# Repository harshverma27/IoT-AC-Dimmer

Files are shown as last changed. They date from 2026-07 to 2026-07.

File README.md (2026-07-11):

# IoT AC Dimmer

ESP32-based wireless phase-angle AC dimmer. Two PCBs linked over ESP-NOW:
a mains-side dimmer board that switches a TRIAC, and a battery-powered
remote with three buttons. Source spec: `IoT AC Dimmer Project.docx`
(v2.0, March 2026).

## What's in this repo

- **Dimmer board** (`hardware/dimmer/`) — 230V mains input, zero-cross
  detection, phase-angle TRIAC control (up to ~2000W / 12A), ESP32 DevKit V1
  running ESP-NOW RX + WiFi.
- **Remote board** (`hardware/remote/`) — LiPo-powered, 3 tactile buttons
  (UP / DOWN / ON-OFF), ESP32 DevKit V1 in deep sleep, ESP-NOW TX only.
- **Generator scripts** (`hardware/tools/`) — Python scripts (on top of
  `kiutils`) that bootstrapped the schematic captures for both boards, so
  the design is reproducible and diffable.

Both boards are designed in KiCad 10. Schematics for both boards are
captured and validated against a `kicad-cli`-exported netlist. PCB layout
is in progress (remote board has a first-pass placement + routing; dimmer
board layout is next).

## Repo layout

```
hardware/
  dimmer/     KiCad project — mains dimmer board (schematic + PCB)
  remote/     KiCad project — battery remote board (schematic + PCB)
  tools/      Python scripts that generated the schematic captures
IoT AC Dimmer Project.docx   Design spec (source of truth for requirements)
CLAUDE.md                    Detailed design notes, GPIO maps, part list
```

See `hardware/README.md`, `hardware/tools/README.md`, and `CLAUDE.md` for
full detail — part lists, GPIO pin maps, and design rationale.

## ⚠️ Safety notice

The dimmer board connects directly to 230V AC mains. It uses an opto-isolated
zero-cross detector (TLP281-4) and an opto-isolated TRIAC driver (MOC3021)
to keep mains-side and logic-side circuitry galvanically isolated, with a
routed FR4 isolation slot under both optoisolators. Do not bridge that
isolation slot with copper or traces, and do not power the dimmer board from
mains and USB at the same time. If you build this, treat it as a mains-voltage
project: use proper enclosures, creepage/clearance spacing, and fusing, and
follow your local electrical code. Build and use at your own risk.

## Hardware overview

### Dimmer board

| Block | Part | Notes |
|---|---|---|
| MCU | ESP32 DevKit V1 (30-pin plug-in module) | Core 0: phase timing ISR. Core 1: WiFi/ESP-NOW/MQTT |
| PSU | HLK-PM03 | Isolated 230V→3.3V/900mA, feeds DevKit 3V3 directly (no LDO) |
| AC in/out | MKDSN 5.08mm screw terminals | Live + Neutral |
| Zero-cross detect | TLP281-4 opto + 1N4007 + resistors | 3.3V pulses into GPIO34 |
| Gate drive | MOC3021 opto + resistor | Drives TRIAC gate from GPIO25 |
| Power switch | BT138-600 TRIAC + gate resistor + RC snubber | ~2000W max (12A) |
| Programming | Onboard CP2102 + micro-USB on the DevKit itself | No separate USB circuitry on the carrier board |

### Remote board

| Block | Part | Notes |
|---|---|---|
| Battery | LiPo 500mAh 3.7V, JST-PH | Rechargeable |
| Charger | TP4056 charge/protect module (USB-C) | Handles charging, protection, and status LEDs |
| LDO | ME6211 3.3V SOT-23-5 | Regulates battery voltage down to clean 3.3V |
| MCU | ESP32 DevKit V1 (30-pin plug-in module) | ext1 button wakeup, ESP-NOW TX, deep sleep between presses |
| Buttons | 3× 6×6mm tactile THT, pull-up + debounce RC | UP / DOWN / ON-OFF |

Full GPIO maps, exact part numbers, and design rationale (including the
plug-in-DevKit battery-life tradeoff on the remote) live in `CLAUDE.md`.

## Getting started

Requires KiCad 10.

```bash
kicad hardware/dimmer/dimmer.kicad_pro
kicad hardware/remote/remote.kicad_pro
```

The `.kicad_sch` files are KiCad-7 format; KiCad 10 opens and upgrades them
automatically. Don't hand-edit the format version token — see
`hardware/tools/README.md` for why.

To regenerate a schematic capture from the Python generators:

```bash
cd hardware/tools
pip install kiutils
python3 gen_dimmer.py
python3 gen_remote.py
python3 validate.py ../dimmer/dimmer.kicad_sch ../remote/remote.kicad_sch
```

## Status

- Schematics: captured and validated for both boards.
- PCB layout: remote board has first-pass placement/routing; dimmer board
  layout not yet started.
- Firmware: not yet in this repo.

## Firmware plan (not yet implemented)

- Dimmer: hardware timer ISR on Core 0 sets TRIAC fire delay after each
  zero crossing (phase-angle dimming). Networking (WiFi/ESP-NOW/MQTT)
  stays on Core 1.
- Remote: wake on button press (`ext1`), send an ESP-NOW packet, go back
  to deep sleep.
- Future: MQTT + OTA on the dimmer; BLE + display on the remote.

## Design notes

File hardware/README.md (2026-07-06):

# Hardware

Two KiCad 10 boards. See root `CLAUDE.md` for the full design spec.

| Dir | Board | Notes |
|-----|---|---|
| `dimmer/` | Mains-side AC dimmer | 230V, TRIAC phase control, ESP-NOW RX + WiFi. **Isolation slot required.** |
| `remote/` | Battery remote | LiPo, 3 buttons, ESP-NOW TX, deep sleep |

Each dir holds `*.kicad_pro` / `*.kicad_sch` / `*.kicad_pcb`.

## Status
- **Schematics: captured** for both boards (`dimmer.kicad_sch`, `remote.kicad_sch`).
  Validated by `kicad-cli` netlist export — every functional net matches intent.
- **PCB layout: not started** (`*.kicad_pcb` still blank) — next phase.

The capture was bootstrapped by the scripts in `tools/` (see `tools/README.md`);
the `.kicad_sch` files are the source of truth.

| Board | Parts placed | Key nets |
|---|---|---|
| dimmer | 31 | mains L/N/L_OUT, ZC detect → GPIO34, gate drive → GPIO25, +3V3/+5V, USB/UART, auto-reset |
| remote | 34 | VBUS/VBAT/+3V3 power path, BTN_UP/DOWN/ONOFF (GPIO39/34/35), USB/UART, auto-reset |

## Workflow
- Open a board: `kicad hardware/dimmer/dimmer.kicad_pro`
  (schematics are KiCad-7 format `20230121`; KiCad 9/10 opens and upgrades them).
- Next: assign/refine footprints, then lay out the PCB — remember the **isolation
  slot** under U2/U3 on the dimmer.
- Analysis / review / BOM / fab: use the **kicad-happy** skills (kicad, bom, jlcpcb, emc…).

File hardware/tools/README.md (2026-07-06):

# Schematic capture generator

Scripts that generated the initial schematic capture for both boards. The
`.kicad_sch` files are the source of truth — these scripts just bootstrapped
them so the capture is reproducible and reviewable in a diff.

| File | Purpose |
|---|---|
| `schlib.py` | Thin KiCad-schematic builder on top of [`kiutils`](https://pypi.org/project/kiutils/): embeds stdlib symbols, builds custom rectangular symbols, places parts, and wires nets with labels + power ports. |
| `parts.py` | Custom symbols for parts / modules absent from the KiCad standard library (HLK-PM03, TLP281-4, MOC3021, ME6211, ESP32-DevKitC-30 plug-in module, TP4056 charge+protect module), with datasheet-accurate pinouts. |
| `gen_dimmer.py` | Builds `../dimmer/dimmer.kicad_sch`. |
| `gen_remote.py` | Builds `../remote/remote.kicad_sch`. |
| `validate.py` | ERC-lite: rebuilds the netlist from geometry + label names and reports nets / floating pins. |

## Regenerate

```bash
pip install kiutils
# KiCad standard symbol libraries are read from /usr/share/kicad/symbols
python3 gen_dimmer.py
python3 gen_remote.py
python3 validate.py ../dimmer/dimmer.kicad_sch ../remote/remote.kicad_sch
```

## Validation performed

Both schematics were loaded by a real `kicad-cli` (`sch export netlist`) and the
KiCad-computed netlist was cross-checked against the intended connectivity —
every functional net matches. The only unconnected pins are spare ESP32 GPIOs,
which are intentional (fixed-function boards, no breakout header in the spec).

## File format note

The schematics are written in KiCad-7 schematic format (`version 20230121`),
which is what `kiutils` emits. KiCad 9/10 opens them directly and will offer to
save in the newer format. Do not hand-edit the version token — the per-symbol
`instances` blocks require `>= 20230121` to be read correctly.

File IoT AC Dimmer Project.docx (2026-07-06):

IoT AC Power Dimmer

with ESP32 + ESP-NOW Wireless Remote

Project Design Document | March 2026

Project Summary

A two-board wireless AC dimmer using ESP32 microcontrollers on both the dimmer and remote. The dimmer board connects to 230V mains and uses phase-angle TRIAC control. The remote runs on a 3.7V LiPo battery with USB-C charging via TP4056. Both boards communicate over ESP-NOW..

Parameter | Dimmer Board | Remote Board
MCU | ESP32-WROOM-32 (240MHz dual-core) | ESP32-WROOM-32 (240MHz dual-core)
Wireless | ESP-NOW RX + WiFi (simultaneous) | ESP-NOW TX only (on wakeup)
Power supply | HLK-PM03 (230V→5V direct) | 3.7V LiPo + TP4056
AC control | TLP281-4 + MOC3021 + BT138 | None
Max load | ~2000W (BT138 12A) | —
Phase timing | hw_timer_t Core 0 (hardware ISR) | —
Sleep current | ~120mA (PSU dominant) | ~5µA deep sleep
Battery life | — | ~4-6 months (500mAh LiPo)
Programming | USB-C via CP2102 on-board | USB-C via CP2102 on-board
Future expansion | MQTT over WiFi, OTA updates | BLE, display add-on possible

# 1. Project Overview

We will make both the ESPs communicate with each other and with the remote board’s instruction, the dimmer board will adjust the AC Supply.

# 2. System Architecture

## 2.1 Dimmer board block diagram

Block | Component | Function
AC IN | MKDSN 5.08mm screw terminal | Live + Neutral mains input
Isolated PSU | HLK-PM03 | 230V AC to 3.3V/900mA, isolated. No LDO needed.
ZC detector | TLP281-4 + R1 10kΩ + D1 1N4007 + R2 10kΩ pull-up | Detects mains zero crossings, outputs 3.3V pulses to GPIO34
Gate drive | MOC3021 + R3 330Ω | Optoisolated TRIAC gate trigger from GPIO25
Power switch | BT138-600 TRIAC + R4 470Ω gate + R5+C5 snubber | Controls AC power to load
MCU | ESP32-WROOM-32 | Core 0: phase timing. Core 1: WiFi + ESP-NOW + MQTT
Programming | CP2102 USB-Serial + USB-C + auto-reset circuit | Flash firmware without ST-Link
AC OUT | MKDSN 5.08mm screw terminal | Output to load
PCB slot | Routed cutout in FR4 | Galvanic isolation under TLP281-4 and MOC3021

## 2.2 Remote board block diagram

Block | Component | Function
Battery | LiPo 500mAh 3.7V (JST-PH) | Main power source, rechargeable
Charger | TP4056 module | USB-C to LiPo 1A
LDO | ME6211 3.3V SOT-23-5 | 3.7V LiPo to regulated 3.3V for ESP32
MCU | ESP32-WROOM-32 | Deep sleep, ext1 wakeup on buttons, ESP-NOW TX
Buttons | 3x tactile 6x6mm + 100kΩ pull-up + 100nF debounce | UP / DOWN / ON-OFF
Programming | CP2102 USB-Serial + USB-C | Firmware flashing
Wakeup pins | GPIO39, GPIO34, GPIO35 (RTC GPIOs) | Only RTC GPIOs survive deep sleep for ext1 wakeup

# 3. Circuit Diagrams

## 3.1 Dimmer board

The HLK-PM03 outputs 3.3V directly — no AMS1117 LDO is needed, simplifying the board significantly compared to v1.0. The TLP281-4 ZC detector feeds GPIO34 (input-only RTC GPIO). The MOC3021 gate drive receives its signal from GPIO25 via R3 330Ohm. The BT138 TRIAC fires after a delay set by hw_timer_t on Core 0. The CP2102 USB-Serial chip enables programming directly from USB-C without any external programmer.

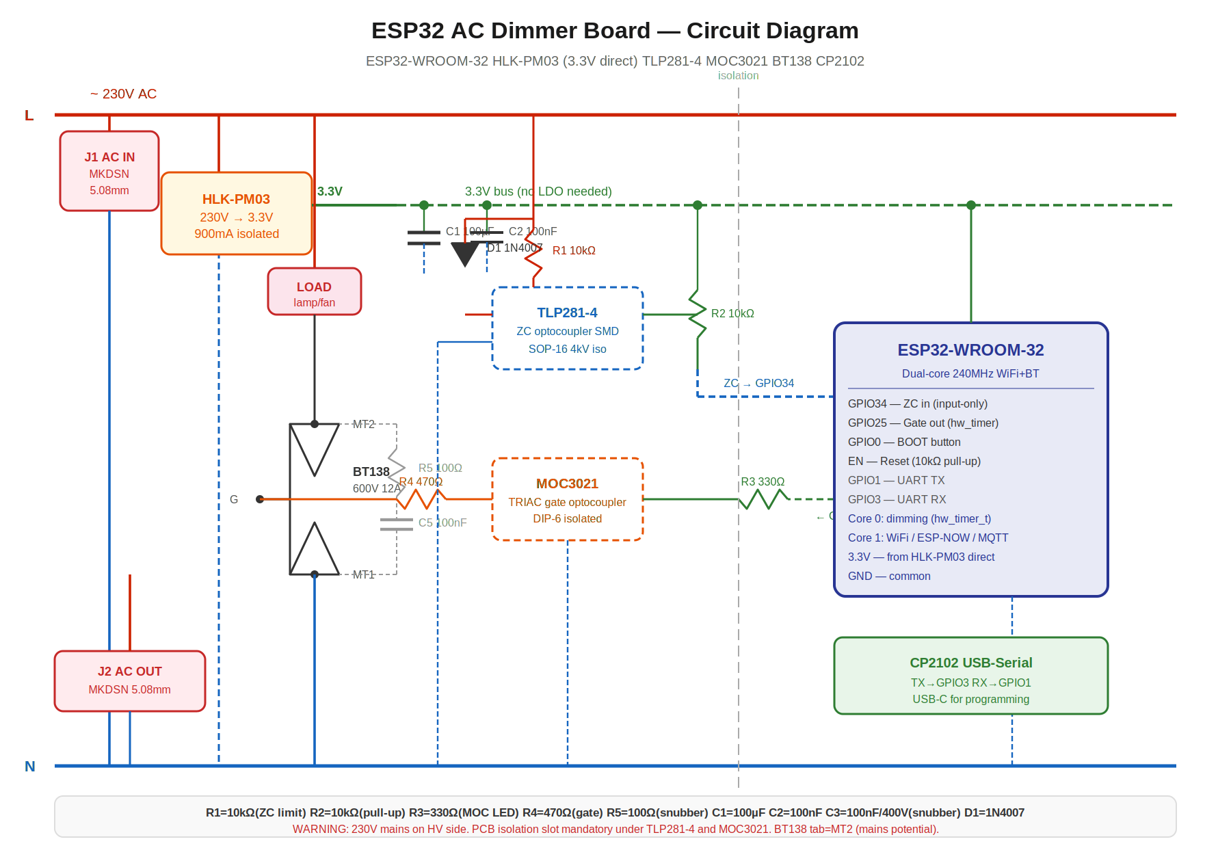
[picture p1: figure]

Figure 1 — ESP32 Dimmer Board. Red rails = 230V AC. Green dashed = 3.3V bus. Note: HLK-PM03 directly outputs 3.3V — no LDO between PSU and ESP32.

## 3.2 Remote board

The LiPo battery feeds the TP4056 charger (which also accepts USB-C input) and the ME6211 LDO simultaneously. The ME6211 regulates 3.7V to a clean 3.3V for the ESP32. Buttons use 100kOhm pull-ups (not 10kOhm) to minimise leakage current during deep sleep. All three button GPIOs (39, 34, 35) are RTC-capable and used with esp_sleep_enable_ext1_wakeup(). The CP2102 provides USB-C programming.

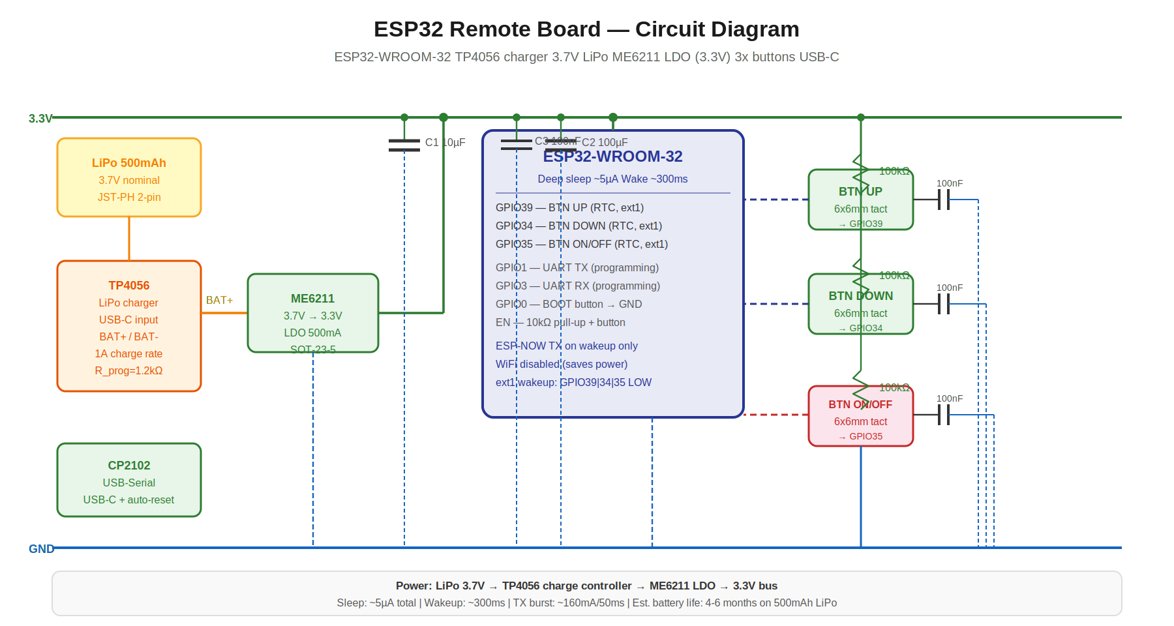
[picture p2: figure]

Figure 2 — ESP32 Remote Board. LiPo + TP4056 + ME6211 power chain. All button pins are RTC GPIOs for deep sleep ext1 wakeup.

# 4. Pin Mapping

## 4.1 Dimmer board — ESP32 GPIO assignments

GPIO | Signal | Direction | Notes
GPIO34 | ZC detect (TLP281-4 output) | Input only | Input-only RTC GPIO. No internal pull-up. Use external 10kOhm pull-up to 3.3V.
GPIO25 | TRIAC gate (MOC3021 LED via R3) | Output | DAC-capable but used as digital. hw_timer_t fires 100us pulse here.

## 4.2 Remote board — ESP32 GPIO assignments

GPIO | Signal | Direction | Notes
GPIO39 | BTN UP | Input only | RTC GPIO. Input-only. External 100kOhm pull-up to 3.3V. ext1 wakeup source.
GPIO34 | BTN DOWN | Input only | RTC GPIO. Input-only. External 100kOhm pull-up. ext1 wakeup source.
GPIO35 | BTN ON/OFF | Input only | RTC GPIO. Input-only. External 100kOhm pull-up. ext1 wakeup source.

Document prepared by Harsh | ESP32 IoT Dimmer Project v2.0 | March 2026

Page Harsh — IoT Dimmer Project

IoT AC Power Dimmer with Wireless Remote

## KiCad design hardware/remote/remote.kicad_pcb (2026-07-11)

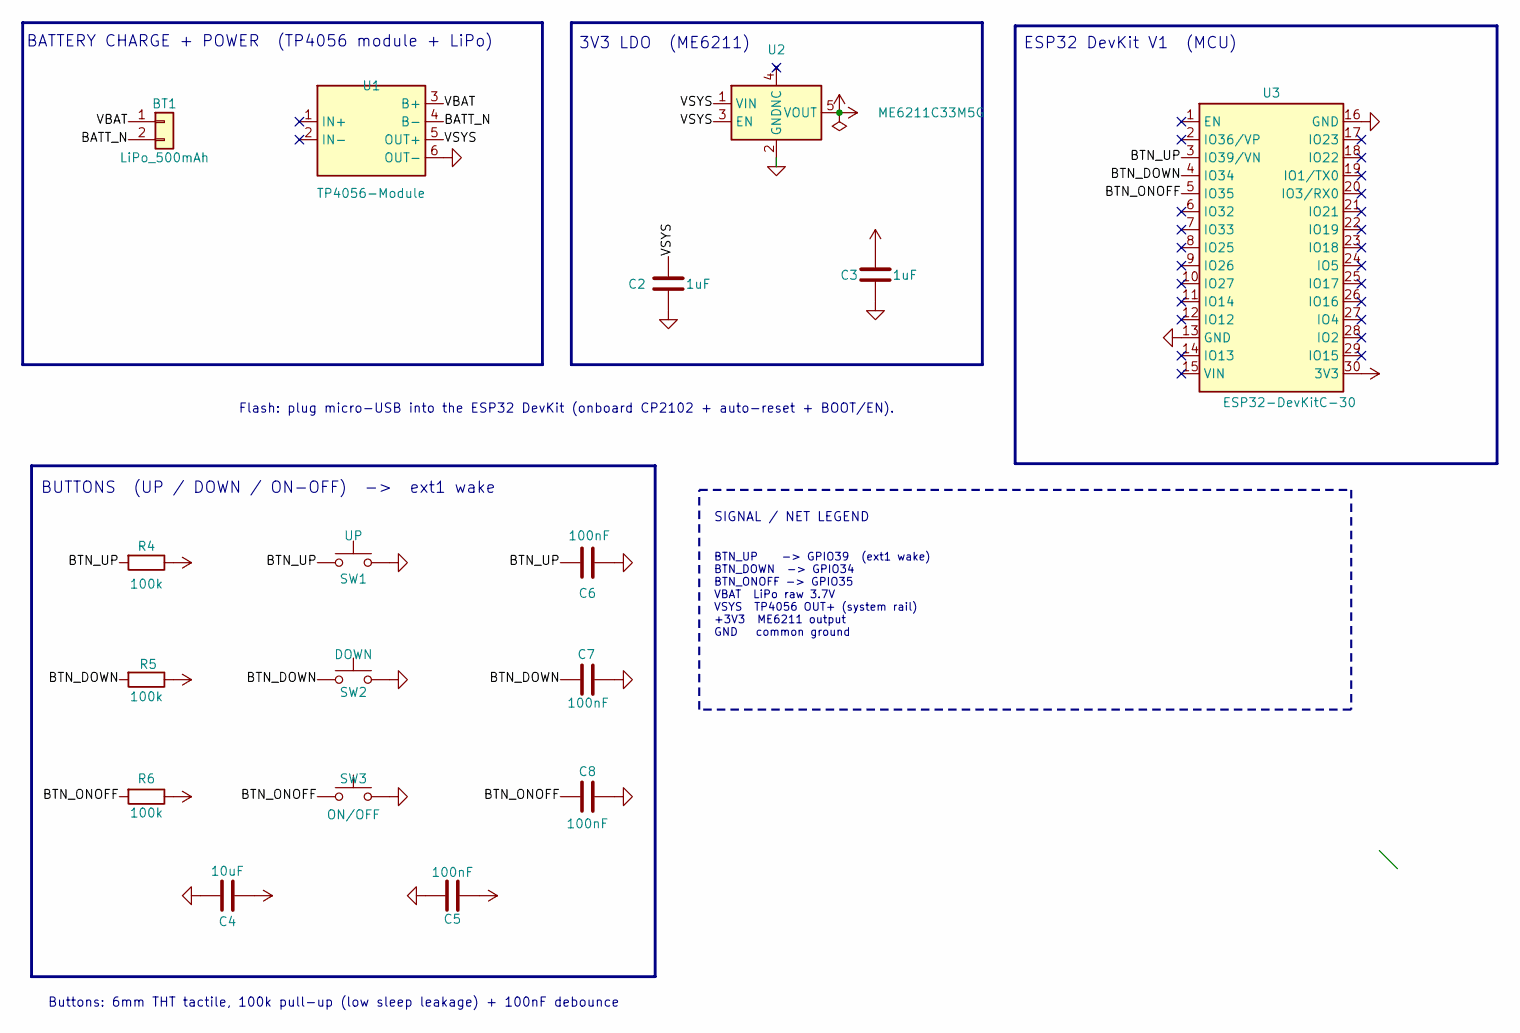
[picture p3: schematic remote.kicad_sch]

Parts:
BT1: LiPo_500mAh; JST_PH_S2B-PH-SM4-TB_1x02-1MP_P2.00mm_Horizontal
C2, C3: 1uF; C_0805_2012Metric
C4: 10uF; C_1206_3216Metric
C5, C6, C7, C8: 100nF; C_0805_2012Metric
R4, R5, R6: 100k; R_0805_2012Metric
SW1: UP; SW_PUSH_6mm
SW2: DOWN; SW_PUSH_6mm
SW3: ON/OFF; SW_PUSH_6mm
U1: TP4056-Module; PinHeader_1x06_P2.54mm_Vertical
U2: ME6211C33M5G; SOT-23-5
U3: ESP32-DevKitC-30

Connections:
+3V3: C3.1, C4.1, C5.1, R4.1, R5.1, R6.1, U2.5 (VOUT), U3.30 (3V3)
/BATT_N: BT1.2, U1.4 (B-)
/BTN_DOWN: C7.1, R5.2, SW2.1, U3.4 (IO34)
/BTN_ONOFF: C8.1, R6.2, SW3.1, U3.5 (IO35)
/BTN_UP: C6.1, R4.2, SW1.1, U3.3 (IO39/VN)
/VBAT: BT1.1, U1.3 (B+)
/VSYS: C2.1, U1.5 (OUT+), U2.1 (VIN), U2.3 (EN)
GND: C2.2, C3.2, C4.2, C5.2, C6.2, C7.2, C8.2, SW1.2, SW2.2, SW3.2, U1.6 (OUT-), U2.2 (GND), U3.13 (GND), U3.16 (GND)

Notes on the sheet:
Flash: plug micro-USB into the ESP32 DevKit (onboard CP2102 + auto-reset + BOOT/EN).
BATTERY CHARGE + POWER (TP4056 module + LiPo)
3V3 LDO (ME6211)
SIGNAL / NET LEGEND
BTN_UP -> GPIO39 (ext1 wake) BTN_DOWN -> GPIO34 BTN_ONOFF -> GPIO35 VBAT LiPo raw 3.7V VSYS TP4056 OUT+ (system rail) +3V3 ME6211 output GND common ground
Buttons: 6mm THT tactile, 100k pull-up (low sleep leakage) + 100nF debounce
BUTTONS (UP / DOWN / ON-OFF) -> ext1 wake
ESP32 DevKit V1 (MCU)

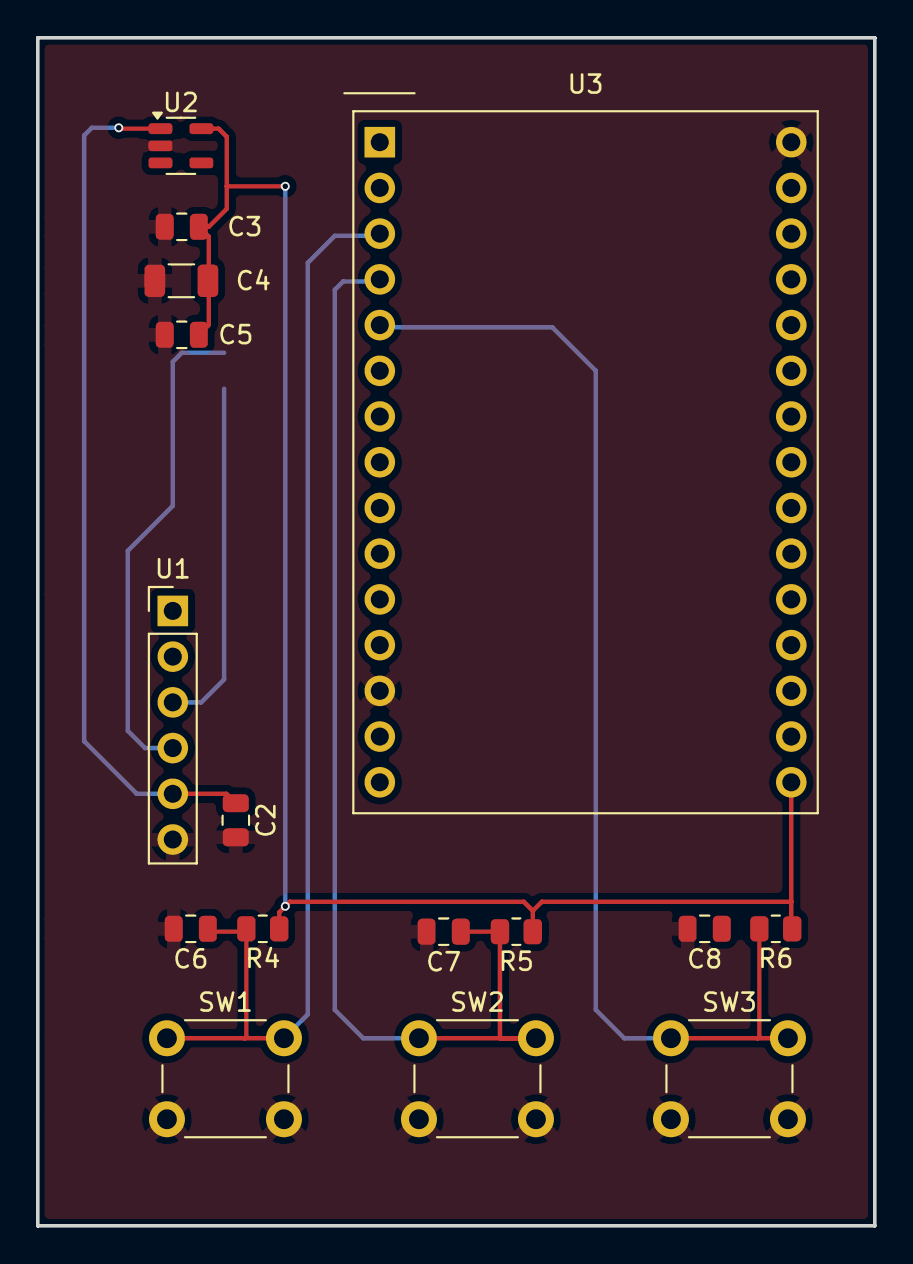
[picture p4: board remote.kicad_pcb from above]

Board: 2 copper layers, 46.5 x 66.0 mm, 17 parts (1 on the bottom side), 8 nets.

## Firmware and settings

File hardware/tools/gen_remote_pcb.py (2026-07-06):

#!/usr/bin/env python3
"""Generate hardware/remote/remote.kicad_pcb from remote.kicad_sch.

First-pass PCB for the battery remote: loads the real KiCad footprints, places
every part in functional groups, assigns the schematic netlist to the pads and
draws the board outline (Edge.Cuts).  Traces and the GND pour are left for the
routing pass -- this establishes placement + full ratsnest.

Netlist is reconstructed from the schematic with validate.py's proven
geometry/label connectivity, so the PCB nets always match the captured design.

Self-check: a courtyard/pad-bbox overlap test runs before writing, since there
is no GUI DRC in this environment.
"""
import os
import sys
import subprocess
import tempfile
from collections import defaultdict
from kiutils.schematic import Schematic
from kiutils.board import Board, Net
from kiutils.footprint import Footprint
from kiutils.items.common import Position, Net as PadNet
from kiutils.items.gritems import GrLine
import validate as V

HERE = os.path.dirname(__file__)
OUT = os.path.join(HERE, "..", "remote", "remote.kicad_pcb")


def fresh_schematic():
    """Emit a fresh kiutils-native (20230121) schematic to a scratch file.

    The committed schematic may have been re-saved by KiCad into a newer format
    that kiutils under-parses (silently dropping power-net pins), so the netlist
    is always taken from the generator's own output, never the committed file.
    """
    tmp = tempfile.mktemp(suffix=".kicad_sch")
    subprocess.run([sys.executable, os.path.join(HERE, "gen_remote.py")],
                   env={**os.environ, "REMOTE_SCH_OUT": tmp},
                   check=True, stdout=subprocess.DEVNULL)
    return tmp
STOCK = "/usr/share/kicad/footprints"
PROJECT_FP = os.path.join(HERE, "..", "footprints")


# --------------------------------------------------------------------------
# 1. Netlist from the schematic (reuse validate.py connectivity)
# --------------------------------------------------------------------------
def extract(path):
    sch = Schematic().from_file(path)
    pm = V.build_pinmaps(sch)
    uf = V.UF()
    labels = defaultdict(list)
    pin_at = defaultdict(list)

    for it in sch.graphicalItems:
        if getattr(it, "type", None) == "wire" and len(it.points) >= 2:
            pts = [V.key(p.X, p.Y) for p in it.points]
            for a, b in zip(pts, pts[1:]):
                uf.union(a, b)
    for l in sch.labels:
        labels[V.key(l.position.X, l.position.Y)].append(l.text)
    comps = {}
    for s in sch.schematicSymbols:
        lib_id = f"{s.libraryNickname}:{s.entryName}"
        ref = next((p.value for p in s.properties if p.key == "Reference"), "?")
        fp = next((p.value for p in s.properties if p.key == "Footprint"), "")
        if not ref.startswith("#"):
            comps[ref] = fp
        ox, oy = s.position.X, s.position.Y
        for num, (lx, ly, nm, et) in pm.get(lib_id, {}).items():
            pt = V.key(ox + lx, oy - ly)
            if ref.startswith("#PWR"):
                val = next((p.value for p in s.properties if p.key == "Value"), "?")
                labels[pt].append(val)
            elif ref.startswith("#FLG"):
                labels[pt].append("__FLAG__")
            else:
                pin_at[pt].append((ref, num))

    anchor = {}
    for pt, names in labels.items():
        for n in names:
            if n == "__FLAG__":
                continue
            if n in anchor:
                uf.union(pt, anchor[n])
            else:
                anchor[n] = pt

    nets = defaultdict(lambda: {"names": set(), "pins": []})
    for pt in set(labels) | set(pin_at):
        r = uf.find(pt)
        nets[r]["names"].update(n for n in labels.get(pt, []) if n != "__FLAG__")
        nets[r]["pins"].extend(pin_at.get(pt, []))

    named = {}
    for d in nets.values():
        if not d["pins"]:
            continue
        name = sorted(d["names"])[0] if d["names"] else None
        if name is None:
            continue
        named.setdefault(name, [])
        named[name].extend(d["pins"])
    return comps, named


# --------------------------------------------------------------------------
# 2. Footprint loading
# --------------------------------------------------------------------------
def fp_path(lib_id):
    nick, name = lib_id.split(":", 1)
    base = PROJECT_FP if nick == "IoT_AC_Dimmer" else STOCK
    return os.path.join(base, f"{nick}.pretty", f"{name}.kicad_mod")


def load_fp(lib_id, ref, value, x, y, angle=0):
    fp = Footprint.from_file(fp_path(lib_id))
    fp.position = Position(x, y, angle)
    for gi in fp.graphicItems:
        t = getattr(gi, "type", None)
        if t == "reference":
            gi.text = ref
        elif t == "value":
            gi.text = value
    return fp


def pad_bbox(fp):
    """Axis-aligned bbox of a placed footprint's pads, in board coords."""
    import math
    a = math.radians(fp.position.angle or 0)
    ca, sa = math.cos(a), math.sin(a)
    xs, ys = [], []
    for p in fp.pads:
        px, py = p.position.X, p.position.Y
        rx = px * ca - py * sa + fp.position.X
        ry = px * sa + py * ca + fp.position.Y
        sx = (p.size.X if p.size else 1) / 2
        sy = (p.size.Y if p.size else 1) / 2
        xs += [rx - sx, rx + sx]
        ys += [ry - sy, ry + sy]
    return min(xs), min(ys), max(xs), max(ys)


# --------------------------------------------------------------------------
# 3. Placement (mm, KiCad board coords: +y is down)
# --------------------------------------------------------------------------
#   ref -> (x, y, angle).  Left column = power/charge + buttons; right = DevKit.
PLACE = {
    "BT1": (12, 8, 0),      # JST-PH battery
    "U1": (10, 18, 0),      # TP4056 module (1x6 header)
    "U2": (28, 12, 0),      # ME6211 LDO
    "C2": (23, 20, 0),      # VSYS in cap
    "C3": (33, 20, 0),      # 3V3 out cap
    "C4": (30, 30, 0),      # 3V3 bulk
    "C5": (37, 30, 0),      # 3V3 100nF
    "U3": (56, 30, 0),      # ESP32 DevKit (big)
    # three button groups, each a vertical stack: pull-up / debounce / button
    "R4": (11, 42, 0), "C6": (11, 47, 0), "SW1": (11, 53, 0),   # UP
    "R5": (25, 42, 0), "C7": (25, 47, 0), "SW2": (25, 53, 0),   # DOWN
    "R6": (39, 42, 0), "C8": (39, 47, 0), "SW3": (39, 53, 0),   # ON/OFF
}
BOARD = (78, 60)   # width, height mm


def main():
    comps, nets = extract(fresh_schematic())
    missing = set(comps) - set(PLACE)
    if missing:
        sys.exit(f"no placement for: {sorted(missing)}")

    board = Board.create_new()
    # net table: 0 = unconnected, then one per named net
    net_num = {"": 0}
    board.nets = [Net(0, "")]
    for i, name in enumerate(sorted(nets), start=1):
        net_num[name] = i
        board.nets.append(Net(i, name))
    pad_net = {}   # (ref, pad) -> (num, name)
    for name, pins in nets.items():
        for ref, pad in pins:
            pad_net[(ref, pad)] = (net_num[name], name)

    placed = {}
    for ref, lib_id in comps.items():
        x, y, ang = PLACE[ref]
        value = ref  # value text not critical for layout; keep ref
        fp = load_fp(lib_id, ref, value, x, y, ang)
        for pad in fp.pads:
            num, nm = pad_net.get((ref, str(pad.number)), (0, ""))
            pad.net = PadNet(num, nm)
        board.footprints.append(fp)
        placed[ref] = fp

    # ---- self-check: pad-bbox overlaps (clearance 0.8mm) -----------------
    CLR = 0.8
    boxes = {r: pad_bbox(f) for r, f in placed.items()}
    clashes = []
    refs = sorted(boxes)
    for i in range(len(refs)):
        for j in range(i + 1, len(refs)):
            a, b = boxes[refs[i]], boxes[refs[j]]
            if (a[0] - CLR < b[2] and b[0] - CLR < a[2] and
                    a[1] - CLR < b[3] and b[1] - CLR < a[3]):
                clashes.append((refs[i], refs[j]))
    # also flag anything outside the board outline
    outside = [r for r, bx in boxes.items()
               if bx[0] < 1 or bx[1] < 1 or bx[2] > BOARD[0] - 1 or bx[3] > BOARD[1] - 1]

    # ---- board outline (Edge.Cuts rectangle) -----------------------------
    w, h = BOARD
    corners = [(0, 0), (w, 0), (w, h), (0, h), (0, 0)]
    for (x1, y1), (x2, y2) in zip(corners, corners[1:]):
        board.graphicItems.append(GrLine(
            start=Position(x1, y1), end=Position(x2, y2),
            layer="Edge.Cuts", width=0.15))

    board.to_file(os.path.abspath(OUT))
    Board().from_file(os.path.abspath(OUT))   # sanity re-read

    print("wrote", os.path.abspath(OUT))
    print(f"footprints={len(board.footprints)} nets={len(board.nets)-1} "
          f"board={w}x{h}mm")
    print("pad-bbox clashes:", clashes or "none")
    print("outside outline:", outside or "none")
    if clashes or outside:
        sys.exit("PLACEMENT PROBLEM - fix PLACE/BOARD")


if __name__ == "__main__":
    main()

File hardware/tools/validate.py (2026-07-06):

#!/usr/bin/env python3
"""ERC-lite: rebuild the netlist from a generated .kicad_sch purely from
geometry and report nets + floating pins.  Independent cross-check of the
generator's intent (catches wrong pin numbers, net-name typos, missing joins).
"""
import sys
from collections import defaultdict
from kiutils.schematic import Schematic

Q = 100.0  # quantise to 0.01 mm


def key(x, y):
    return (round(x * Q), round(y * Q))


def build_pinmaps(sch):
    pm = {}
    ext = {}
    byname = {}
    for s in sch.libSymbols:
        lib_id = f"{s.libraryNickname}:{s.entryName}"
        byname[lib_id] = s
        d = {}
        for u in s.units:
            for p in u.pins:
                d[p.number] = (p.position.X, p.position.Y, p.name, p.electricalType)
        pm[lib_id] = d
        if s.extends:
            ext[lib_id] = f"{s.libraryNickname}:{s.extends}"
    # resolve extends (child inherits parent pins)
    for lib_id in list(pm):
        cur = lib_id
        chain = []
        while cur in ext:
            chain.append(ext[cur])
            cur = ext[cur]
        for parent in chain:
            for k, v in pm.get(parent, {}).items():
                pm[lib_id].setdefault(k, v)
    return pm


class UF:
    def __init__(self):
        self.p = {}

    def find(self, a):
        self.p.setdefault(a, a)
        while self.p[a] != a:
            self.p[a] = self.p[self.p[a]]
            a = self.p[a]
        return a

    def union(self, a, b):
        self.p[self.find(a)] = self.find(b)


def analyse(path):
    sch = Schematic().from_file(path)
    pm = build_pinmaps(sch)
    uf = UF()
    labels = defaultdict(list)   # point -> [netname]
    pin_at = defaultdict(list)   # point -> [(ref,pinnum,name,etype)]
    nc_pts = set()

    # wires
    for it in sch.graphicalItems:
        if getattr(it, "type", None) == "wire" and len(it.points) >= 2:
            pts = [key(p.X, p.Y) for p in it.points]
            for a, b in zip(pts, pts[1:]):
                uf.union(a, b)

    # labels
    for l in sch.labels:
        labels[key(l.position.X, l.position.Y)].append(l.text)
    for l in sch.globalLabels:
        labels[key(l.position.X, l.position.Y)].append(l.text)

    # no-connects
    for nc in sch.noConnects:
        nc_pts.add(key(nc.position.X, nc.position.Y))

    # symbol pins + power ports
    for s in sch.schematicSymbols:
        lib_id = f"{s.libraryNickname}:{s.entryName}"
        ref = next((p.value for p in s.properties if p.key == "Reference"), "?")
        val = next((p.value for p in s.properties if p.key == "Value"), "?")
        ox, oy = s.position.X, s.position.Y
        for num, (lx, ly, nm, et) in pm.get(lib_id, {}).items():
            pt = key(ox + lx, oy - ly)
            if ref.startswith("#PWR"):
                labels[pt].append(val)            # power port names its net
            elif ref.startswith("#FLG"):
                labels[pt].append("__FLAG__")
            else:
                pin_at[pt].append((ref, num, nm, et))

    # local labels of identical text on one sheet are the same net: union all
    # points that carry a given label name (KiCad name-based connectivity).
    name_anchor = {}
    for pt, names in labels.items():
        for n in names:
            if n == "__FLAG__":
                continue
            if n in name_anchor:
                uf.union(pt, name_anchor[n])
            else:
                name_anchor[n] = pt

    # every point that carries anything is a node; merge coincident points are
    # already same key. Nets = connected components.
    nets = defaultdict(lambda: {"names": set(), "pins": []})
    all_pts = set(labels) | set(pin_at) | set(nc_pts)
    for pt in all_pts:
        r = uf.find(pt)
        for n in labels.get(pt, []):
            nets[r]["names"].add(n)
        for pininfo in pin_at.get(pt, []):
            nets[r]["pins"].append(pininfo)

    # report
    named = {}
    for r, d in nets.items():
        realnames = sorted(n for n in d["names"] if n != "__FLAG__")
        name = realnames[0] if realnames else f"<unnamed@{r}>"
        named.setdefault(name, {"pins": [], "aliases": set()})
        named[name]["pins"] += d["pins"]
        named[name]["aliases"] |= set(realnames)

    print(f"\n=== {path} ===")
    print(f"symbols={len(sch.schematicSymbols)} libsyms={len(sch.libSymbols)} "
          f"wires={sum(1 for i in sch.graphicalItems if getattr(i,'type',None)=='wire')} "
          f"labels={len(sch.labels)} nc={len(sch.noConnects)} nets={len(named)}")

    # floating: component pins that are alone on a net and not no_connect
    nc_set = set()
    for pt in nc_pts:
        for pininfo in pin_at.get(pt, []):
            nc_set.add((pininfo[0], pininfo[1]))
    floating = []
    multi = 0
    for name, d in named.items():
        if len(d["pins"]) >= 2:
            multi += 1
        for (ref, num, nm, et) in d["pins"]:
            if len(d["pins"]) < 2 and (ref, num) not in nc_set and et != "no_connect":
                floating.append((name, ref, num, nm, et))

    print(f"multi-pin nets={multi}")
    print("\n-- key nets --")
    for name in sorted(named):
        if name.startswith("<unnamed"):
            continue
        pins = named[name]["pins"]
        if not pins:
            continue
        tag = ",".join(f"{r}.{n}({nm})" for r, n, nm, et in sorted(pins))
        print(f"  {name:12} [{len(pins)}] {tag}")

    print("\n-- FLOATING pins (single-pin nets, not NC) --")
    if floating:
        for name, ref, num, nm, et in sorted(floating):
            print(f"  !! {ref}.{num} {nm} ({et})  net={name}")
    else:
        print("  none")
    return floating


if __name__ == "__main__":
    for p in sys.argv[1:]:
        analyse(p)

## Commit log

2026-07-06 Scaffold KiCad projects for dimmer + remote boards
    Add two blank KiCad 10 projects under hardware/ (dimmer, remote), a
    hardware README, and .gitignore for KiCad/fab artifacts. Document the
    full design spec and repo layout in CLAUDE.md. Include the source
    design doc.
    [dimmer.kicad_pcb, dimmer.kicad_sch, remote.kicad_pcb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]
2026-07-06 Capture dimmer + remote board schematics
    Populate the previously-blank KiCad schematics for both boards per the
    project spec, and add the Python generators that bootstrapped them.
    Dimmer (mains, isolated): ESP32-WROOM-32, HLK-PM03 PSU, AC in/out screw
    terminals, TLP281-4 zero-cross detect (R1/D1/R2 -> GPIO34), MOC3021 opto-TRIAC
    gate drive (R3 <- GPIO25), BT138-600 TRIAC + gate resistor + RC snubber,
    CP2102 USB-serial with USB-C and two-transistor auto-reset. Mains nets kept
    separate from the 3V3/GND logic domain (isolation barrier).
    Remote (battery): USB-C -> TP4056 charger -> LiPo -> ME6211 LDO -> 3V3 rail,
    ESP32-WROOM-32, three tactile buttons on RTC GPIOs (39/34/35) each with a 100k
    pu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
    [dimmer.kicad_sch, remote.kicad_sch]
2026-07-06 Untrack .history dirs, resolve KiCad-generated schematic diffs
    Match main's earlier cleanup: drop .history submodule tracking and
    ignore it. Also picks up KiCad-normalized sheet UUIDs and schematic
    formatting from opening both projects in KiCad 10.
    [dimmer.kicad_sch, remote.kicad_sch]
2026-07-06 hardware: switch both boards to plug-in modules (ESP32 DevKit, TP4056)
    Rework the schematic capture so every part maps to a hand-solderable module
    or component you can buy from Robu / Robocraze / Quartz Components, per the
    "hand-solder from modules" plan.
    Both boards:
    - Replace the bare ESP32-WROOM-32 + the entire onboard USB-serial subsystem
    (CP2102 QFN, board USB-C + CC resistors, two-transistor auto-reset, CP2102
    support caps/pull-ups, separate BOOT/EN buttons) with a plug-in ESP32
    DevKit V1 (30-pin) that carries its own USB bridge, micro-USB, auto-reset
    and BOOT/EN. Carrier now only routes 3V3/GND + the GPIOs it uses.
    Remote:
    - TP4056 bare SOP-8 -> TP4056 charge+protect module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
    [dimmer.kicad_sch, remote.kicad_sch]
2026-07-06 hardware: annotate both schematics with block boxes, headers, net legend
    Add color-coded functional-block rectangles, colored block-title text,
    and a signal/net-legend glossary to the dimmer and remote schematics for
    readability. Also upgrades both .kicad_sch to KiCad 10 format. Netlist
    connectivity verified unchanged on both boards (dimmer 12 nets, remote 8).
    [dimmer.kicad_sch, remote.kicad_sch]
2026-07-06 hardware(remote): first-pass PCB layout (placement + netlist + outline)
    Bootstraps the remote board PCB from the captured schematic.
    - gen_remote_pcb.py: kiutils-based PCB generator. Loads real KiCad footprints,
    places every part in functional groups (charge/power on the left, DevKit on
    the right, three button stacks along the bottom), assigns the full schematic
    netlist to the pads, and draws the Edge.Cuts outline (78x60mm). Includes a
    pad-bbox overlap self-check (no GUI DRC here). Traces + GND pour are the next
    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
    [dimmer.kicad_sch, remote.kicad_pcb, remote.kicad_sch]
2026-07-06 pcb: Update PCB design and Child item name
    [remote.kicad_pcb, remote.kicad_sch]
2026-07-11 hardware(remote): PCB layout tweaks, README rewrite, ignore ERC/DRC reports
    Claude-Session: https://claude.ai/code/session_01EpJvfsWNhnzVoGz5gYoJZP
    [remote.kicad_pcb]
